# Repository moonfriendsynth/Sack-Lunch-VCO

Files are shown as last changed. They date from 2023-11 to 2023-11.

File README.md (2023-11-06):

# Sack-Lunch-VCO
A simple AS3340-based VCO for eurorack

This VCO was designed using a number of open source schematics as well as the AS3340's data sheet. It is nothing fancy, but it gets the job done, like a sack lunch.\

You can find the schematic here as well as gerbers for the PCBs and front panel. If you want to make your own front panel, you can use the edgecuts files here to get the exact outline.

<b>If you want to print this yourself</b>
<br>Please be aware, I have made a few changes to these gerbers since I last printed them. The changes were minor, but I have not verified them myself. Print at your own (very small) risk.
<br><br>To print, download <a href="https://github.com/moonfriendsynth/Sack-Lunch-VCO/blob/2d1b4b25dfa2b1dbcb76dec84105f6ccebe1b944/Sack%20Lunch%20VCO%20Board%20A%20Gerber.zip">Sack Lunch VCO Board A Gerbers.zip</a>, <a href="https://github.com/moonfriendsynth/Sack-Lunch-VCO/blob/2d1b4b25dfa2b1dbcb76dec84105f6ccebe1b944/Sack%20Lunch%20VCO%20Board%20B%20Gerber.zip">Sack Lunch VCO Board B Gerbers.zip</a>, and <a href="https://github.com/moonfriendsynth/Sack-Lunch-VCO/blob/2d1b4b25dfa2b1dbcb76dec84105f6ccebe1b944/VCO%20Front%20Plate/VCO%20Gerbers/VCO%20Front%20Plate%20Gerbers.zip">VCO Front Plate Gerbers.zip</a>. I used JLCPCB to print mine, and you can probably get these for about $10-15 plus shipping (which is another $15). Or email me moonfriendsynth@gmail.com and I'll send you the previous version (which still works just as good with two minor changes) for like $5.

<b>Features</b>
1. 3 waveform outputs 10vpp
2. Hard Sync input
3. PWM for square wave, with a range from 50% to 0% (at the far clockwise on the knob, 0%, the waveform becomes silent)
4. PWM CV input - when CV is patched in, the PWM nob becomes an attenuator for the CV
5. Linear FM input with attenuator knob
6. Fine and coarse frequency knobs 
7. LED status light. This is optional and it's only purpose is to add some extra color to your rack
8. Stable tuning, as is typical of the AS3340. Once you initially tune the circuit, you likely won't need to fiddle with the trimmers in the back ever again
9. 2 forms of circuit protection: schottky diodes on the power rails, which will prevent damage in the case of polarity reversal, and a shrowded box header on the power pins. Apparently a lot of companies do not use these box headers, which is confusing since they are super cheap and they have the benefit of physically preventing you from pluggin power in backward. Seems like a no-brainer. 
10. A little owl, hanging out
11. A topographical map of Mount Rainier in the background, if you ever find yourself lost out there with only your trusty VCO to guide you

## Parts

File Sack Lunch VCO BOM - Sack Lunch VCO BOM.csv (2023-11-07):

Moon Friend Synth
Sack Lunch VCO Bill of Materials
Version 1 Revision 3
Reference(s) | Qty | Value | Notes | Link to buy
C1, C4, C10 | 3 | 47u |  | https://www.taydaelectronics.com/47uf-50v-105c-radial-electrolytic-capacitor-6x11mm.html
C2, C6, C8, C9, C15, C16 | 6 | 0.1UF |  | https://www.taydaelectronics.com/10-x-0-1uf-50v-ceramic-disc-capacitor-pkg-of-10.html
C3, C5, C11, C12 | 4 | 10 NF |  | https://www.taydaelectronics.com/10nf-0-01uf-100v-5-polyester-film-box-type-capacitor.html
C7 | 1 | 1 NF | Must be polyester film | https://www.taydaelectronics.com/wima-fks2-100nf-0-001uf-100v-5-polyester-film-box-type-capacitor.html
C13, C14 | 2 | 10u |  | https://www.taydaelectronics.com/10uf-50v-105c-radial-electrolytic-capacitor-5x11mm.html
D1 | 1 | LED |  | https://www.taydaelectronics.com/leds/round-leds/5mm-leds.html
D2, D3 | 2 | 1n5817 | you can also use a 1n5818 or 1n5819 | https://www.taydaelectronics.com/1n5817-diode-schottky-1a-20v.html
J1, J2, J3, J4, J5, J6, J7 | 7 | Mono jack | The jacks at Tayda are good, but they are not as high quality as the ones can get at Thonk.co.uk | https://www.taydaelectronics.com/hardware/3-5mm-plugs-jacks/pj-3001f-3-5-mm-mono-phone-jack.html
 |  |  |  | https://www.thonk.co.uk/shop/3-5mm-jacks/
J8 | 1 | Conn_02x5 |  | https://www.taydaelectronics.com/10-pin-box-header-connector-2-54mm.html
R27 |  | RL | When in doubt, get 2.2k
R11, R17 |  | 470R
R4 | 1 | 620R | Buy all your resistors using this link | https://www.taydaelectronics.com/resistors/1-4w-metal-film-resistors.html
R28, R29, R30 | 3 | 1K
R13 | 1 | 1.8k | All resistors are 1/4W
R8 | 1 | 5.6k
R1, R10, R19 | 3 | 10K
R7 | 1 | 24k
R5 | 1 | 47k
R3, R6, R12, R14, R25, R26 | 1 | 100K
R15, R23 | 2 | 150K
R24 | 1 | 200K
R18 | 1 | 1M
R16 | 1 | 1.5M
R2 | 1 | 2.2M
R9 | 1 | 5.6M
R20 | 1 | 100k Potentiometer | There are a few different options for potentiometers at Tayda. If you want the top quality, search for Alpha. You can also get different shaft types, just make sure that it is a linear taper | https://www.taydaelectronics.com/tayda-100k-ohm-linear-taper-potentiometer-round-shaft-pcb-9mm-6-35-mm.html
R21, R31, R33 | 3 | Tall Trimmer 100K | If you are in the US, synthcube is probably the place to get these, however, sometimes, the total price from Thonk can be cheaper. If you don't want to make a special order just for these 3 pots, you can find shorter alternatives on Tayda. If you buy normal metal shaft versions, just keep in mind that the holes on the front panel are not big enough. You can probably drill them out pretty easily if you want to go that route | https://synthcube.com/cart/song-huei-9mm-panel-trim-pot-tall?search=song%20huei%20tall&description=true
RP1, RP2, RP3 | 3 | 20k |  | https://www.taydaelectronics.com/potentiometer-variable-resistors/cermet-potentiometers/20k-ohm-trimmer-potentiometer-cermet-25-turns-3296w.html
U1 | 1 | TL074 |  | https://www.taydaelectronics.com/tl074-quad-operational-amplifier-j-fet-pdip-14-tl074cn.html
U2 | 1 | AS3340 | Make sure you buy the correct one!!!! | https://synthcube.com/cart/alfa-rpar-as3340-as3340a-vco-ic?search=As3340&description=true
 |  |  | UK link | https://www.thonk.co.uk/shop/alpha-as-series-ic-chips/
IC Adapter | 1 | 14 pin |  | https://www.taydaelectronics.com/14-pin-dip-ic-socket-adaptor-solder-type.html
IC Adapter | 1 | 16 pin |  | https://www.taydaelectronics.com/16-pin-dip-ic-socket-adaptor-solder-type.html
Header Male | 2 | 01x05, 2.54mm | You might just want to get a big 40 version of these and cut them down as you need them | https://www.taydaelectronics.com/5-pin-2-54-mm-single-row-pin-header-strip.html
Header Female | 2 | 01x05, 2.54mm |  | https://www.taydaelectronics.com/5-pin-2-54-mm-single-row-female-pin-header.html
Standoff | 1 | M3x10mm | optional, extra stability | https://www.taydaelectronics.com/brass-standoff-spacer-screw-hex-male-m3x10mm-golden.html
Nut | 1 | M3 | buy this if you get the standoff | https://www.taydaelectronics.com/nut-3mm-for-screw-m3.html
Screw | 1 | M3x6mm | buy this if you get the standoff | https://www.taydaelectronics.com/m3-steel-screw-cross-round-head-m3x6mm.html

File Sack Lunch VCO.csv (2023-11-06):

Source: | C:\Users\Steve\Documents\Sack Lunch VCO\Sack Lunch VCO.kicad_sch
Date: | 1/26/2022 9:38:41 PM
Tool: | Eeschema (6.0.0)
Generator: | E:\Program Files\KiCad\6.0\bin\scripting\plugins/bom_csv_grouped_by_value.py
Component Count: | 63
Individual Components:
Item | Qty | Reference(s) | Value | LibPart | Footprint | Datasheet
 |  | C1 | 47u | Device:C_Polarized_Small |  | ~
 |  | C2 | 0.1UF | Device:C_Small |  | ~
 |  | C3 | 10 NF | Device:C_Small |  | ~
 |  | C4 | 47u | Device:C_Polarized_Small |  | ~
 |  | C5 | 10 NF | Device:C_Small |  | ~
 |  | C6 | 0.1 UF | Device:C_Small |  | ~
 |  | C7 | 1 NF | Device:C_Small |  | ~
 |  | C8 | 0.1 UF | Device:C_Small |  | ~
 |  | C9 | 0.1 UF | Device:C_Small |  | ~
 |  | C10 | 47u | Device:C_Polarized_Small |  | ~
 |  | C11 | 10 NF | Device:C_Small |  | ~
 |  | C12 | 10 NF | Device:C_Small |  | ~
 |  | C13 | 10u | Device:C_Polarized_Small |  | ~
 |  | C14 | 10u | Device:C_Polarized_Small |  | ~
 |  | C15 | 0.1UF | Device:C_Small |  | ~
 |  | C16 | 0.1UF | Device:C_Small |  | ~
 |  | D1 | LED | Device:LED |  | ~
 |  | J1 | FM | Connector:AudioJack2_Ground |  | ~
 |  | J2 | PWM | Connector:AudioJack2_Ground |  | ~
 |  | J3 | SYNC | Connector:AudioJack2_Ground |  | ~
 |  | J4 | V/OCT | Connector:AudioJack2_Ground |  | ~
 |  | J5 | PULSE | Connector:AudioJack2_Ground |  | ~
 |  | J6 | TRI | Connector:AudioJack2_Ground |  | ~
 |  | J7 | SAW | Connector:AudioJack2_Ground |  | ~
 |  | J8 | Conn_01x10 | Connector_Generic:Conn_01x10 |  | ~
 |  | R1 | 10K | Device:R |  | ~
 |  | R2 | 2.2M | Device:R |  | ~
 |  | R3 | 100K | Device:R |  | ~
 |  | R4 | 620R | Device:R |  | ~
 |  | R5 | 47k | Device:R |  | ~
 |  | R6 | 100K | Device:R |  | ~
 |  | R7 | 24k | Device:R |  | ~
 |  | R8 | 5.6k | Device:R |  | ~
 |  | R9 | 5.6M | Device:R |  | ~
 |  | R10 | 10K | Device:R |  | ~
 |  | R11 | 470R | Device:R |  | ~
 |  | R12 | 100K | Device:R |  | ~
 |  | R13 | 1.8k | Device:R |  | ~
 |  | R14 | 100K | Device:R |  | ~
 |  | R15 | 150K | Device:R |  | ~
 |  | R16 | 1.5M | Device:R |  | ~
 |  | R17 | 470R | Device:R |  | ~
 |  | R18 | 1M | Device:R |  | ~
 |  | R19 | 10K | Device:R |  | ~
 |  | R20 | COURSE TUNE | Device:R_Potentiometer | Potentiometer_THT:Potentiometer_Alpha_RD901F-40-00D_Single_Vertical_CircularHoles | ~
 |  | R21 | FINE TUNE | Device:R_Potentiometer | Potentiometer_THT:Potentiometer_Alpha_RD901F-40-00D_Single_Vertical_CircularHoles | ~
 |  | R22 | 10R | Device:R |  | ~
 |  | R23 | 150K | Device:R |  | ~
 |  | R24 | 200K | Device:R |  | ~
 |  | R25 | 100K | Device:R |  | ~
 |  | R26 | 100K | Device:R |  | ~
 |  | R27 | RL | Device:R |  | ~
 |  | R28 | 1K | Device:R |  | ~
 |  | R29 | 1K | Device:R |  | ~
 |  | R30 | 1K | Device:R |  | ~
 |  | R31 | FM AMOUNT | Device:R_Potentiometer | Potentiometer_THT:Potentiometer_Alpha_RD901F-40-00D_Single_Vertical_CircularHoles | ~
 |  | R32 | 10R | Device:R |  | ~
 |  | R33 | PWM AMOUNT | Device:R_Potentiometer | Potentiometer_THT:Potentiometer_Alpha_RD901F-40-00D_Single_Vertical_CircularHoles | ~
 |  | RP1 | 20k | Device:R_Potentiometer_Trim_US |  | ~
 |  | RP2 | 20k | Device:R_Potentiometer_Trim_US |  | ~
 |  | RP3 | 20k | Device:R_Potentiometer_Trim_US |  | ~
 |  | U1 | TL074 | Amplifier_Operational:TL074 |  | http://www.ti.com/lit/ds/symlink/tl071.pdf
 |  | U2 | AS3340 | Audio:AS3340 |  | http://www.alfarzpp.lv/eng/sc/AS3340.pdf
Collated Components:
Item | Qty | Reference(s) | Value | LibPart | Footprint | Datasheet
1 | 3 | C1, C4, C10 | 47u | Device:C_Polarized_Small |  | ~
2 | 3 | C2, C15, C16 | 0.1UF | Device:C_Small |  | ~
3 | 4 | C3, C5, C11, C12 | 10 NF | Device:C_Small |  | ~
4 | 3 | C6, C8, C9 | 0.1 UF | Device:C_Small |  | ~
5 | 1 | C7 | 1 NF | Device:C_Small |  | ~
6 | 2 | C13, C14 | 10u | Device:C_Polarized_Small |  | ~
7 | 1 | D1 | LED | Device:LED |  | ~
8 | 1 | J1 | FM | Connector:AudioJack2_Ground |  | ~
9 | 1 | J2 | PWM | Connector:AudioJack2_Ground |  | ~
10 | 1 | J3 | SYNC | Connector:AudioJack2_Ground |  | ~
11 | 1 | J4 | V/OCT | Connector:AudioJack2_Ground |  | ~
12 | 1 | J5 | PULSE | Connector:AudioJack2_Ground |  | ~
13 | 1 | J6 | TRI | Connector:AudioJack2_Ground |  | ~
14 | 1 | J7 | SAW | Connector:AudioJack2_Ground |  | ~
15 | 1 | J8 | Conn_01x10 | Connector_Generic:Conn_01x10 |  | ~
16 | 3 | R1, R10, R19 | 10K | Device:R |  | ~
17 | 1 | R2 | 2.2M | Device:R |  | ~
18 | 6 | R3, R6, R12, R14, R25, R26 | 100K | Device:R |  | ~
19 | 1 | R4 | 620R | Device:R |  | ~
20 | 1 | R5 | 47k | Device:R |  | ~
21 | 1 | R7 | 24k | Device:R |  | ~
22 | 1 | R8 | 5.6k | Device:R |  | ~
23 | 1 | R9 | 5.6M | Device:R |  | ~
24 | 2 | R11, R17 | 470R | Device:R |  | ~
25 | 1 | R13 | 1.8k | Device:R |  | ~
26 | 2 | R15, R23 | 150K | Device:R |  | ~
27 | 1 | R16 | 1.5M | Device:R |  | ~
28 | 1 | R18 | 1M | Device:R |  | ~
29 | 1 | R20 | COURSE TUNE | Device:R_Potentiometer | Potentiometer_THT:Potentiometer_Alpha_RD901F-40-00D_Single_Vertical_CircularHoles | ~
30 | 1 | R21 | FINE TUNE | Device:R_Potentiometer | Potentiometer_THT:Potentiometer_Alpha_RD901F-40-00D_Single_Vertical_CircularHoles | ~
31 | 2 | R22, R32 | 10R | Device:R |  | ~
32 | 1 | R24 | 200K | Device:R |  | ~
33 | 1 | R27 | RL | Device:R |  | ~
34 | 3 | R28, R29, R30 | 1K | Device:R |  | ~
35 | 1 | R31 | FM AMOUNT | Device:R_Potentiometer | Potentiometer_THT:Potentiometer_Alpha_RD901F-40-00D_Single_Vertical_CircularHoles | ~
36 | 1 | R33 | PWM AMOUNT | Device:R_Potentiometer | Potentiometer_THT:Potentiometer_Alpha_RD901F-40-00D_Single_Vertical_CircularHoles | ~
37 | 3 | RP1, RP2, RP3 | 20k | Device:R_Potentiometer_Trim_US |  | ~
38 | 1 | U1 | TL074 | Amplifier_Operational:TL074 |  | http://www.ti.com/lit/ds/symlink/tl071.pdf
39 | 1 | U2 | AS3340 | Audio:AS3340 |  | http://www.alfarzpp.lv/eng/sc/AS3340.pdf

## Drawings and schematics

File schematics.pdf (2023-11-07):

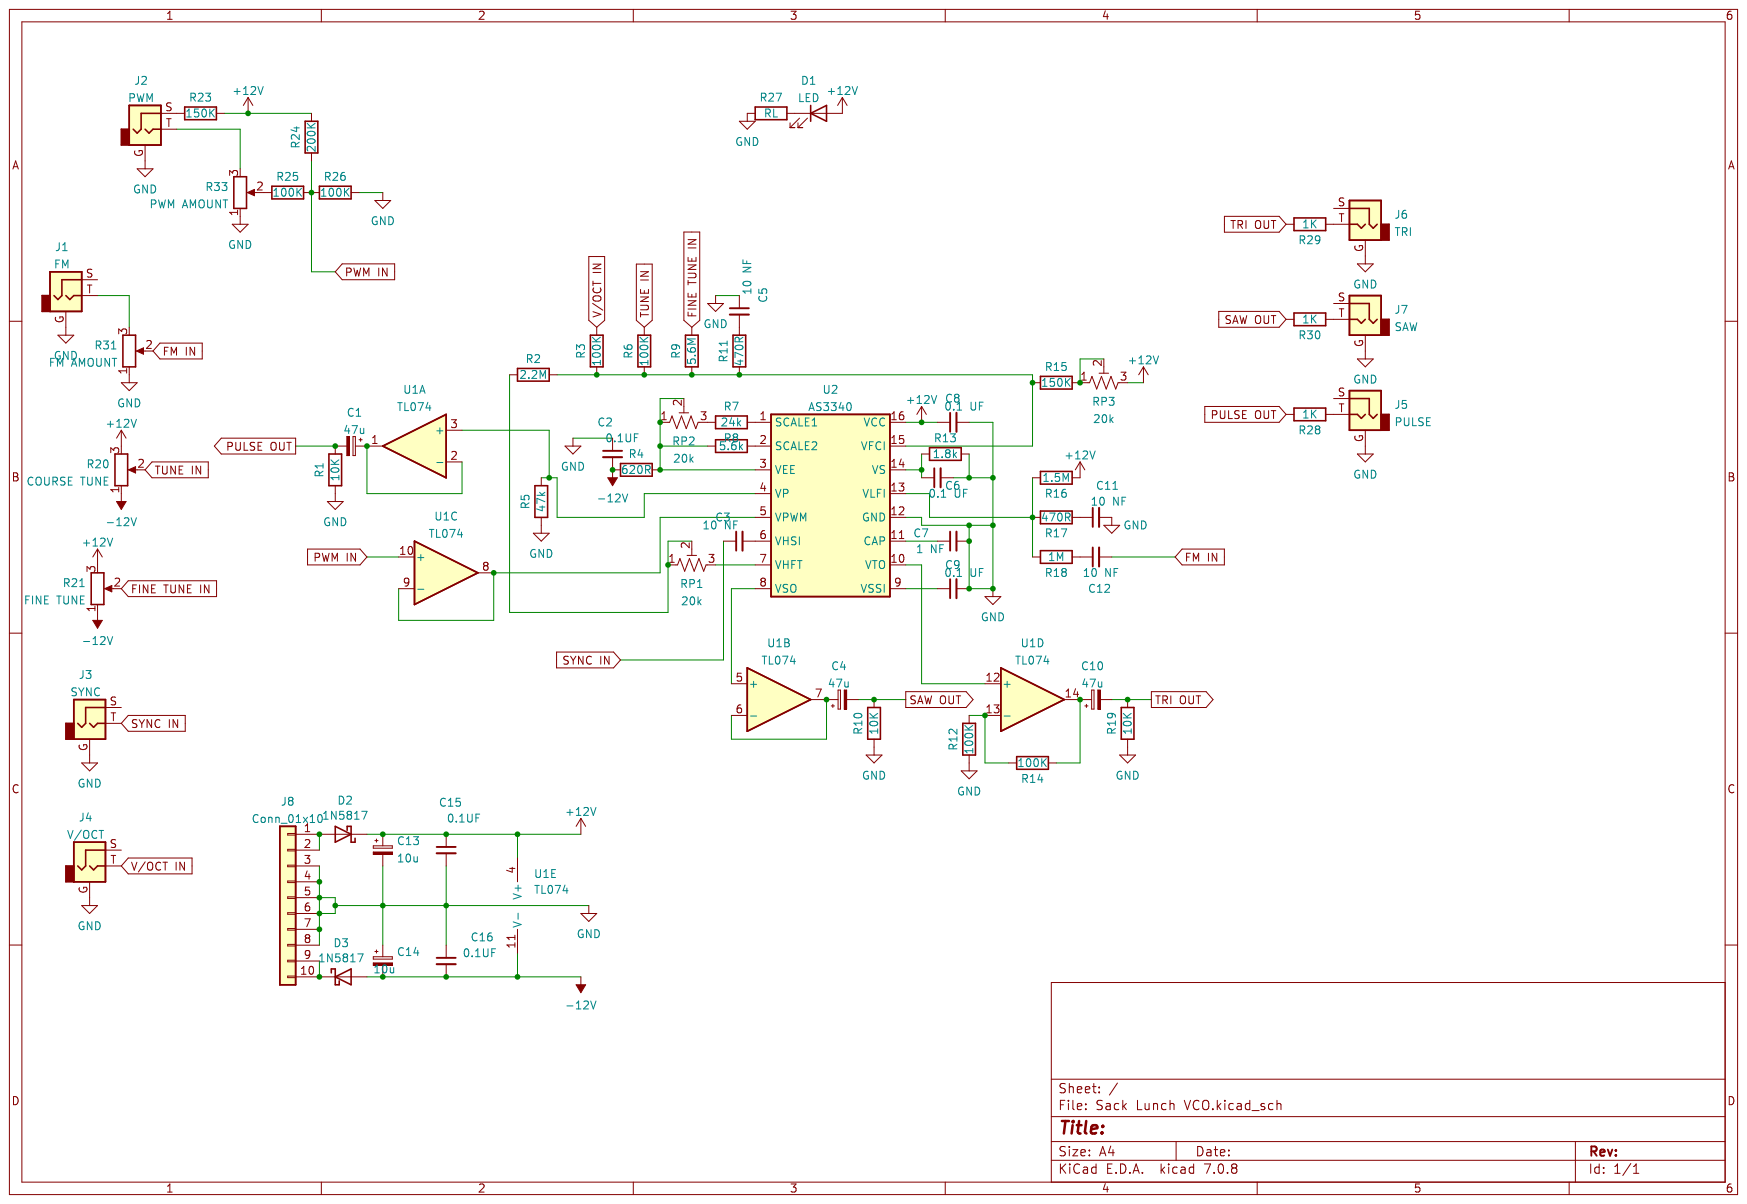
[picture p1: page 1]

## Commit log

2023-11-06 Add files via upload
    Initial upload of KiCad files and schematic
    [Sack Lunch VCO.csv, Sack Lunch VCO.kicad_pcb, Sack Lunch VCO.kicad_sch]
2023-11-06 Add files via upload
    KiCad files for the front panel
    [VCO Front Plate-B_Cu.gbr, VCO Front Plate-B_Mask.gbr, VCO Front Plate-B_Paste.gbr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]
2023-11-06 Update README.md
    Added details on how to print these yourself
2023-11-07 Add files via upload
    Updated schematics
